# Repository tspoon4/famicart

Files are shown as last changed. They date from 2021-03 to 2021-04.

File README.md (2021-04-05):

# Overview
A while ago, I bought a Famicom in Japan with a bunch of game carts (including Super Mario Bros. 3 and The Legend of Zelda 1!).

As a programmer, I always had in mind to run my own program on it and play with this amazing hardware.
As a beginner in electronics, designing a development cartridge would be an great opportunity to learn.

After a bit of googling, I found the Nesdev community and their extensive [knowledge base](http://wiki.nesdev.com/w/index.php/Nesdev_Wiki). For this learning project, I wanted to design the board from scratch by choosing myself the components and discovering the boolean logic to connect them.

I enjoyed studying the various IC datasheets and playing with the Arduino to prototype the PRG-ROM Flasher.
Please note that this project is not optimized for cost and is not a professional development platform.

# Features
* 512KiB PRG-ROM (Flash) split in 16x32KiB banks
* 64KiB PRG-RAM (SRAM) split in 8x8KiB banks, battery backed work RAM
* 16KiB CHR-RAM (SRAM) with 2-4 nametable support
* Simple discrete logic mapper using an 8bit write-only register at address $8000
	* Bit 0-3: PRG-ROM 32KiB bank selection (2^4 = 16)
	* Bit 4-6: PRG-RAM 8KiB bank selection (2^3 = 8)
	* Bit 7: Software mirroring control (horizontal, vertical)
* CHR-RAM memory mapping customization with 2 jumpers
	* Jumper J2: CIRAM enable/disable
	* Jumper J3: Software controlled mirroring/single-screen
* Arduino Uno/Nano PRG-ROM programmer is available at this [location](flash/)
* KiCad source files for modification are available at this [location](kicad/)
* PDF exports for quick review are available at this [location](pdf/)

# Pictures
Images | Images
------ | ------
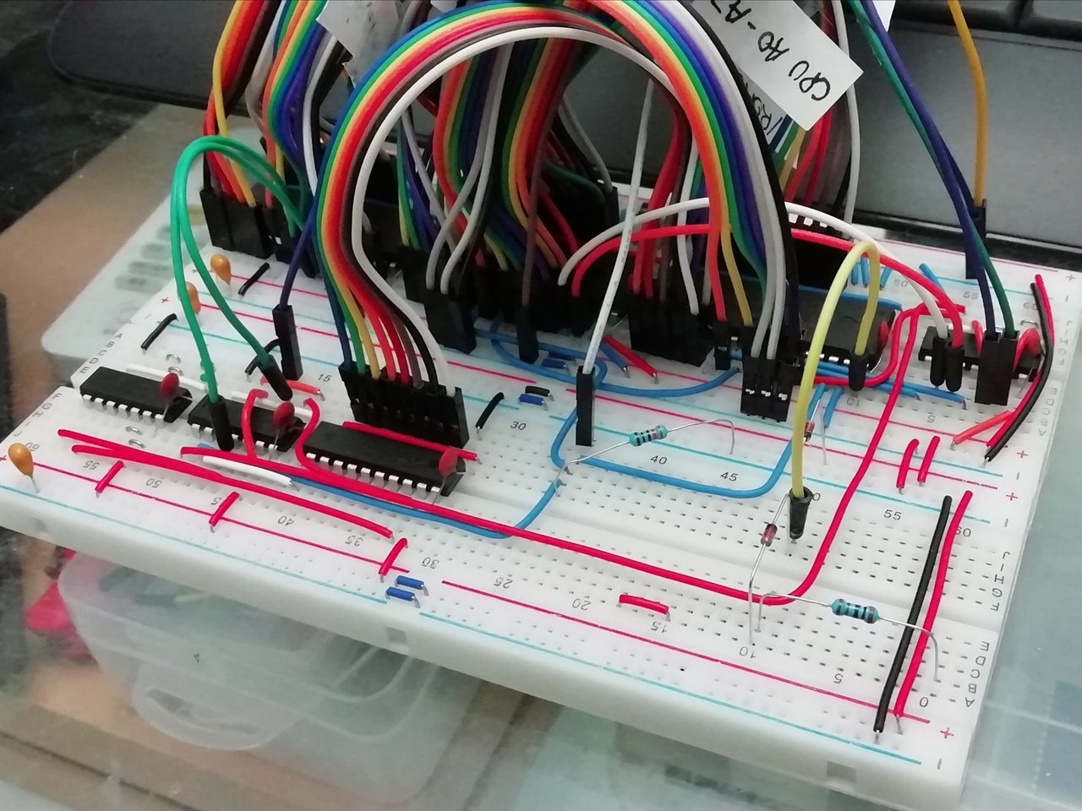
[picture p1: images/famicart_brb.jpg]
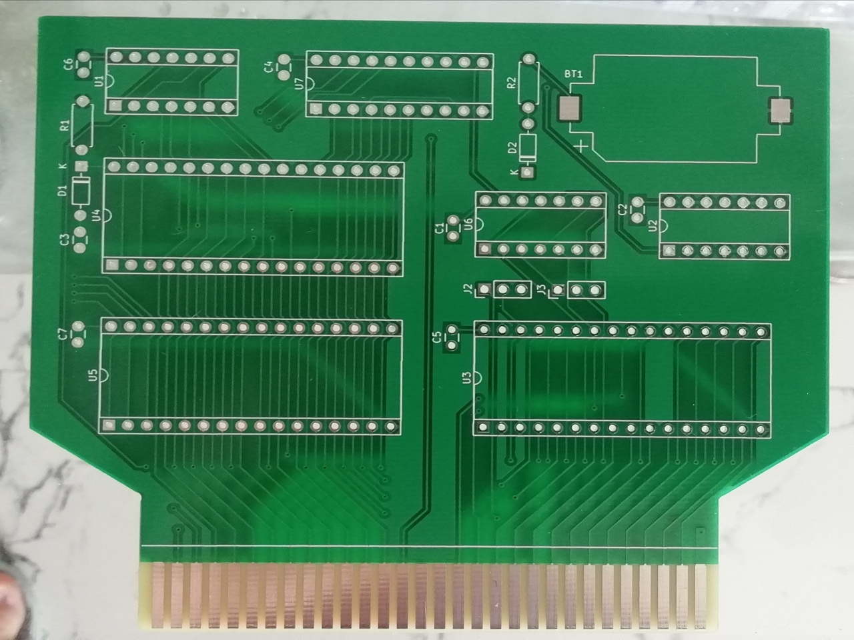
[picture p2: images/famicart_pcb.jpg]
 | 
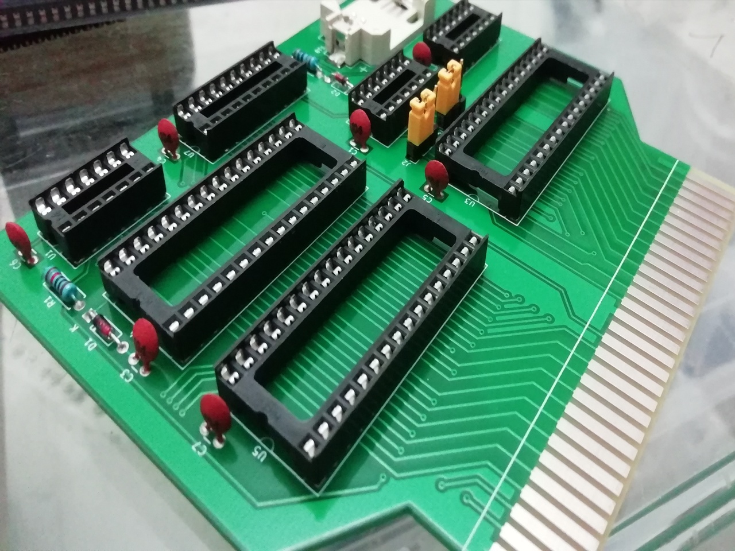
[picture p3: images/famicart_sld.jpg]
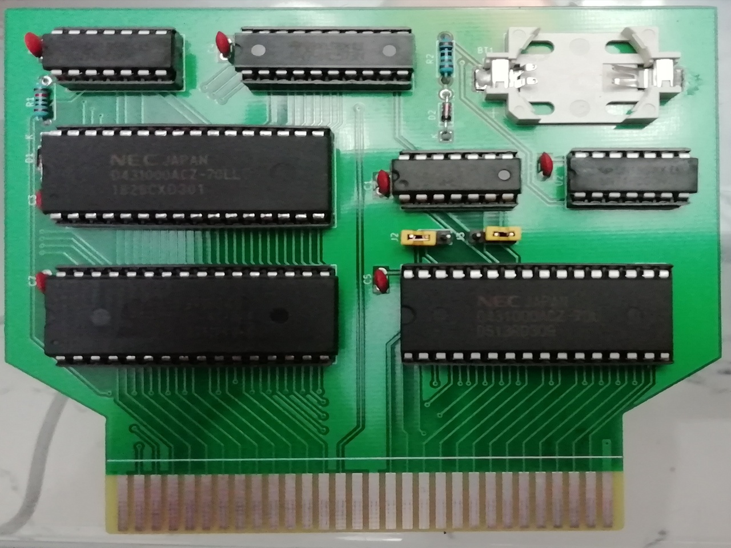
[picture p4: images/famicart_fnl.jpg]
 | 

# Production
To produce the PCB that will fit in the Famicom cartridge slot, you will have to provide to the manufacturer the 2 following items:
* Information that the PCB thickness should be **1.2mm**
* The Gerber files for the different PCB layers from this [location](gerber/)

# Components
Reference | Quantity | Purpose
--------- | -------- | -------
Resistor 1k | 1 | Battery charge protection
Resistor 10k | 1 | Pull down for PRG-RAM
Diode 1N4148 | 2 | Or PRG-RAM power supply
Capacitor 100nF | 7 | Decoupling
Nand 74HC00 | 2 | Decoding PRG R/W signals and misc logic
Nor 74HC02 | 1 | Software controlled mirroring logic
Latch 74HC573 | 1 | Mapper register
Flash SST39SF040 | 1 | PRG-ROM chip
SRAM uPD431000A-70LL | 2 | PRG-RAM and CHR-RAM chip
Conn 3pins | 2 | CHR-RAM jumpers
CR2032 Holder | 1 | 3V battery case

# Potential improvements
### Palette RAM bus conflict when disabling CIRAM
When disabling CIRAM the CHR-RAM is always enabled because:
* CHR-RAM /CE1 is connected to GND
* CHR-RAM CE2 is connected to VCC

CHR-RAM read/write technically mirrors Palette RAM indices but this has not been extensively tested.
### Component packing
Packing is loose and PCB surface use can be improved to reduce costs and fit in a cartridge case.
Vias close to the cartridge connectors might be saved by leveraging memory chip pads.
### CHR-RAM banks instead of PRG-RAM
I've made the choice to implement banking on PRG-RAM instead of CHR-RAM.
It is possible to modify the KiCad source files to use Bit 4-6 of the mapper register to implement banking on CHR-RAM the same way as PRG-RAM.

# References
* [Nesdev wiki](https://wiki.nesdev.com/w/index.php/Cartridge_connector) for the cartridge connector pinout
* [Nesdev forums](https://forums.nesdev.com/viewtopic.php?f=9&t=2162) for the PCB specs and various information
* [KiCad EDA](https://kicad.org/) to edit the PCB source files
* [Arduino Nano](https://store.arduino.cc/usa/arduino-nano) for the links on datasheets
* [NES ca65 example](https://github.com/bbbradsmith/NES-ca65-example) to validate the cartridge features 
* IC Datasheets (TI, SST, NEC)

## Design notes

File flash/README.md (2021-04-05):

# Overview
This folder contains the Famicart SST Flash programmer for the Arduino.

The Arduino program waits for incoming data from the Serial interface.  
It first tries to decode a command and if a command is recognized, it will execute it immediately.  
Input or output data is always transferred from the host PC through the Serial interface.  

The 8bits of data are direcly applied to the SST chip from the Arduino pins.  
The 24bits of address are transferred to the daisy-chained shift registers using the vanilla SPI library.  

The program accepts 3 commands through Serial input:
* **erase**: erases the whole SST chip
* **write \[address\]**: writes at \[address\] the stream of bytes that will follow 
* **read \[address\] \[size\]**: reads at \[address\] an amount of \[size\] bytes and output to tty

# How to use (linux)
Assuming the Arduino is bound to ttyUSB0, first set the device properties
> stty -F /dev/ttyUSB0 speed 115200  
> stty -F /dev/ttyUSB0 raw -echo -echoe -echok  

Then in order to write the SST chip, start by erasing it and then send the command to write the data contained in the program.rom binary file (generally assembled with ca65)
> echo "erase" > /dev/ttyUSB0 ; sleep 1s  
> echo "write 0" > /dev/ttyUSB0 ; cat program.rom > /dev/ttyUSB0  

**Note that in order to succeed, another terminal has to consume the Serial output as follows**
> cat /dev/ttyUSB0  

# Pictures
Image | Image | Image
----- | ----- | -----
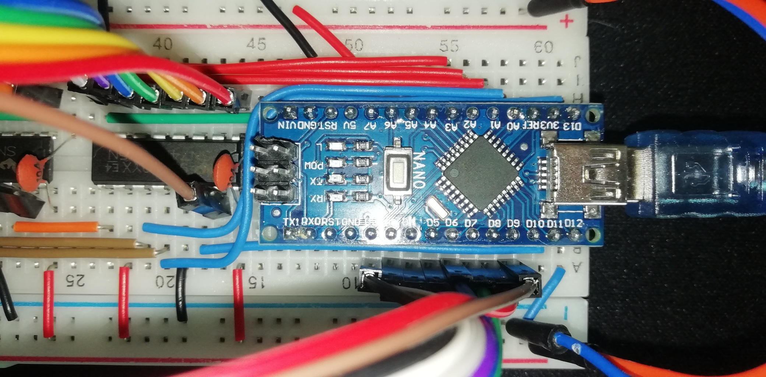
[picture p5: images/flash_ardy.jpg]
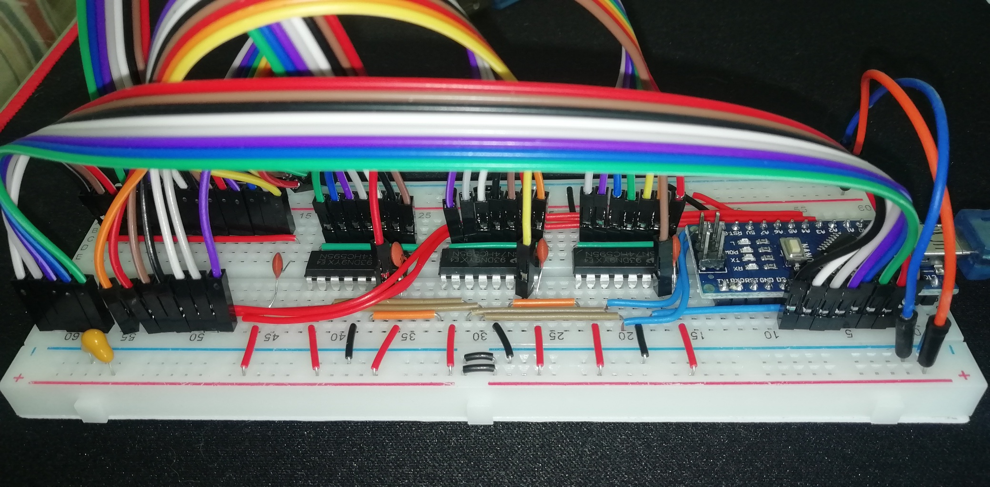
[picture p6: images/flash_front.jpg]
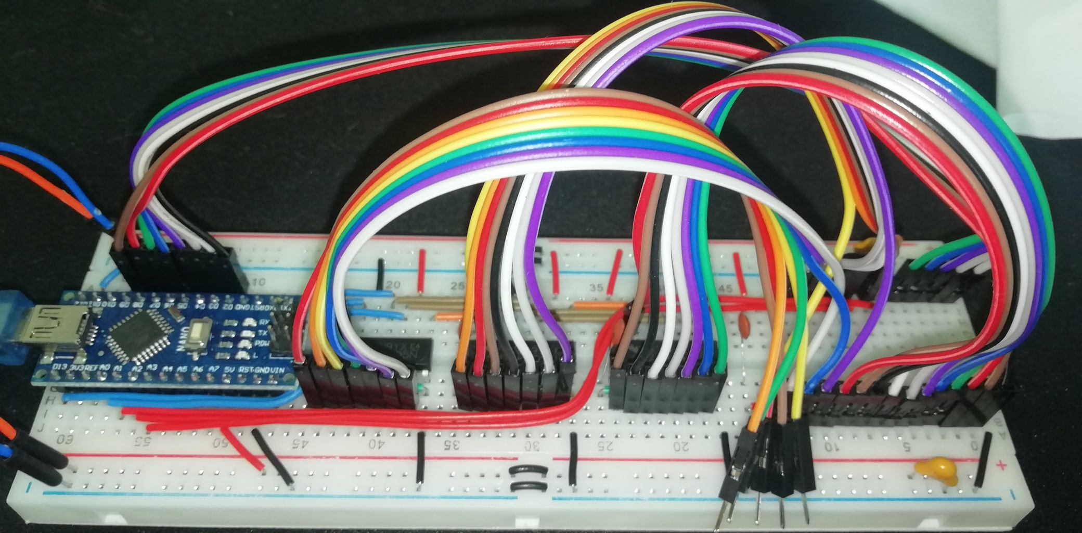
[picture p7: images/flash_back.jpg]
 |  | 

# Components
Reference | Quantity | Purpose
--------- | -------- | -------
Capacitor 100nF | 4 | Decoupling
Capacitor 10uF | 2 | Lower frequency decoupling
Arduino Nano v3.x | 1 | Interface between Host/Flash
Shift 74HC595 | 3 | Arduino pin expansion for address bus (SPI)
Breadboard MB-102 | 1 | A big generic IC socket
Patience | Some | Complete the circuit successfully

# Potential improvements
### Write time is slower than SST theoretical write time
This is probably related to 2 issues:
* Arduino Nano Serial management seems slower than Arduino Uno
* Use of SPI to transfer 24bits addresses (~3us with SPI at 8MHz)

The SST byte program time is ~20us and requires sending 4 commands so 4 addresses in total (~12us). The total time to setup the addresses is not small compared to the byte program time: it's one bottleneck.

It is not possible to set the tty baudrate higher than 115200 without having corruption in this program. This means that the time to transfer a byte is ~87us (3x more than SST byte program time): it's another bottleneck.

As a solution, we can consider using a different microcontroller that has enough pins and supports higher baudrates for Serial transfer.

### Create a PCB
:smile:

# References
* [Arduino SPI reference](https://www.arduino.cc/en/Reference/SPI) to move data to Shift registers
* [Arduino port manipulation](https://www.arduino.cc/en/Reference/PortManipulation) to cut down the pin setup time
* SST Flash Datasheet

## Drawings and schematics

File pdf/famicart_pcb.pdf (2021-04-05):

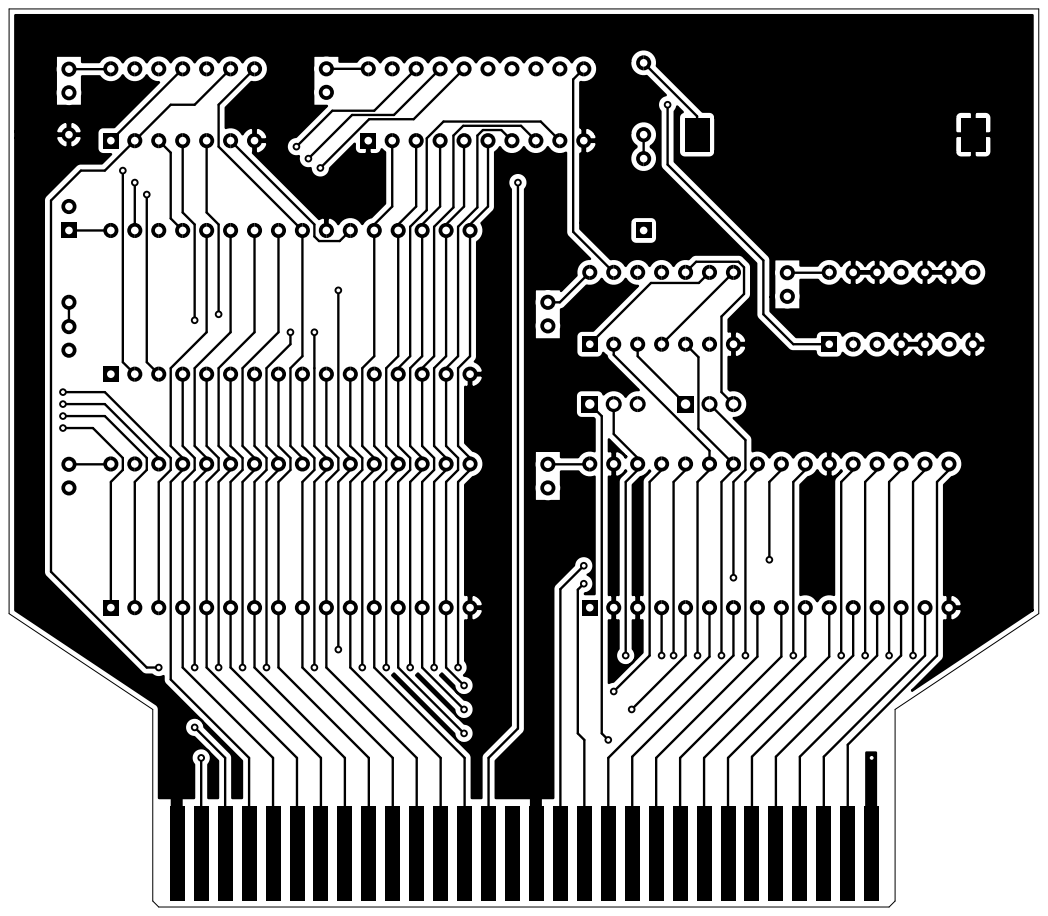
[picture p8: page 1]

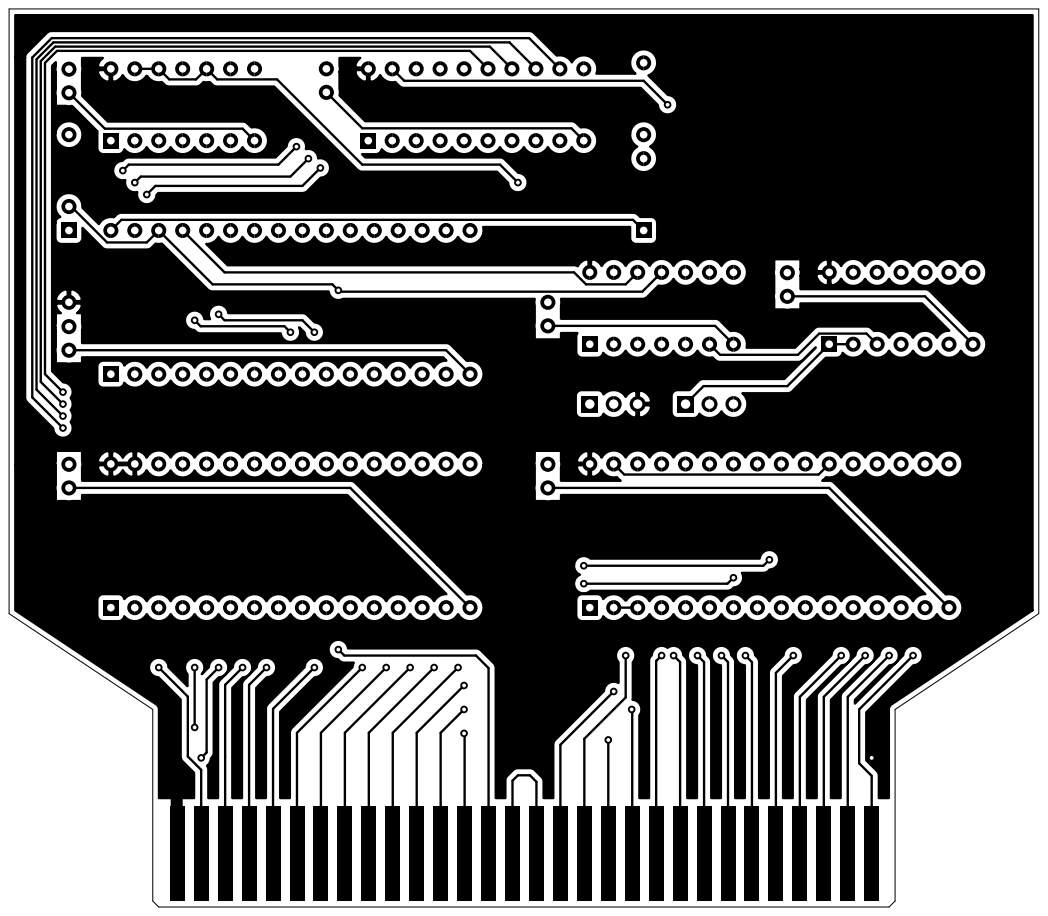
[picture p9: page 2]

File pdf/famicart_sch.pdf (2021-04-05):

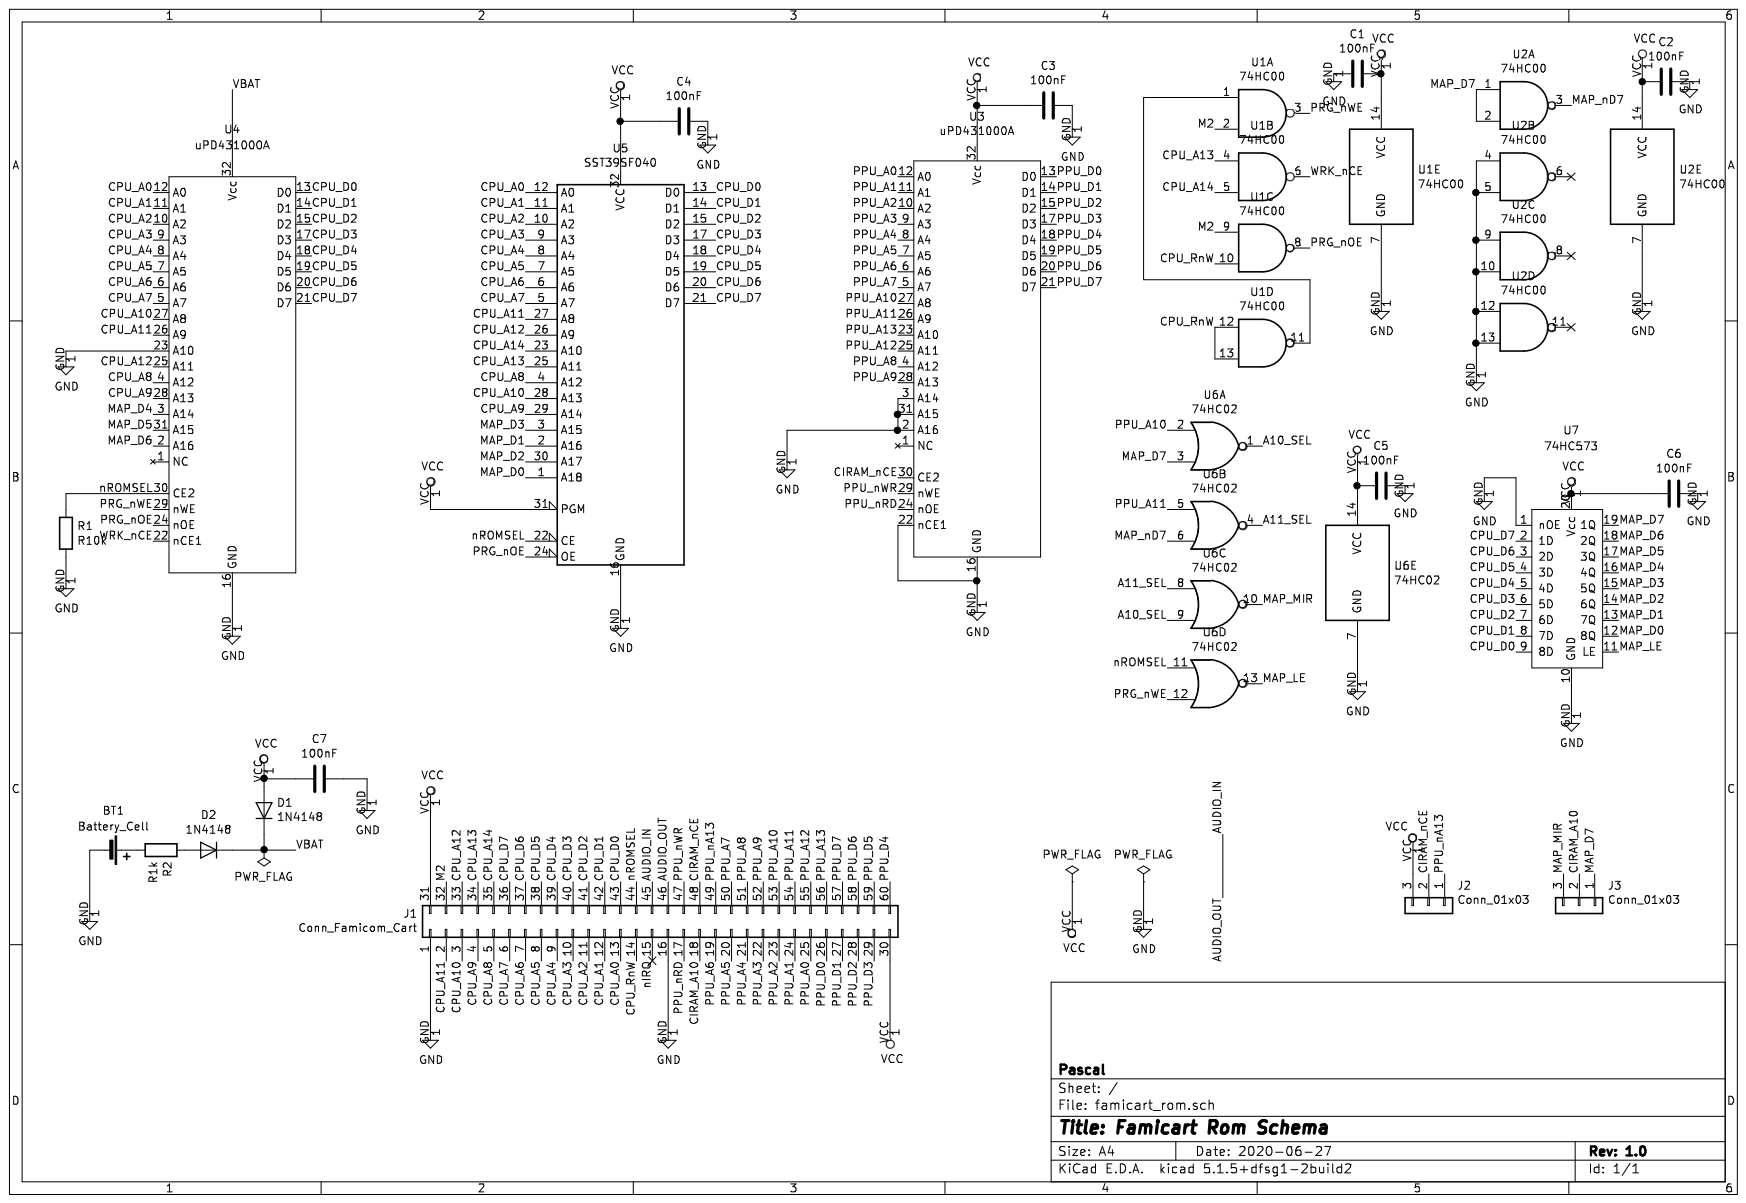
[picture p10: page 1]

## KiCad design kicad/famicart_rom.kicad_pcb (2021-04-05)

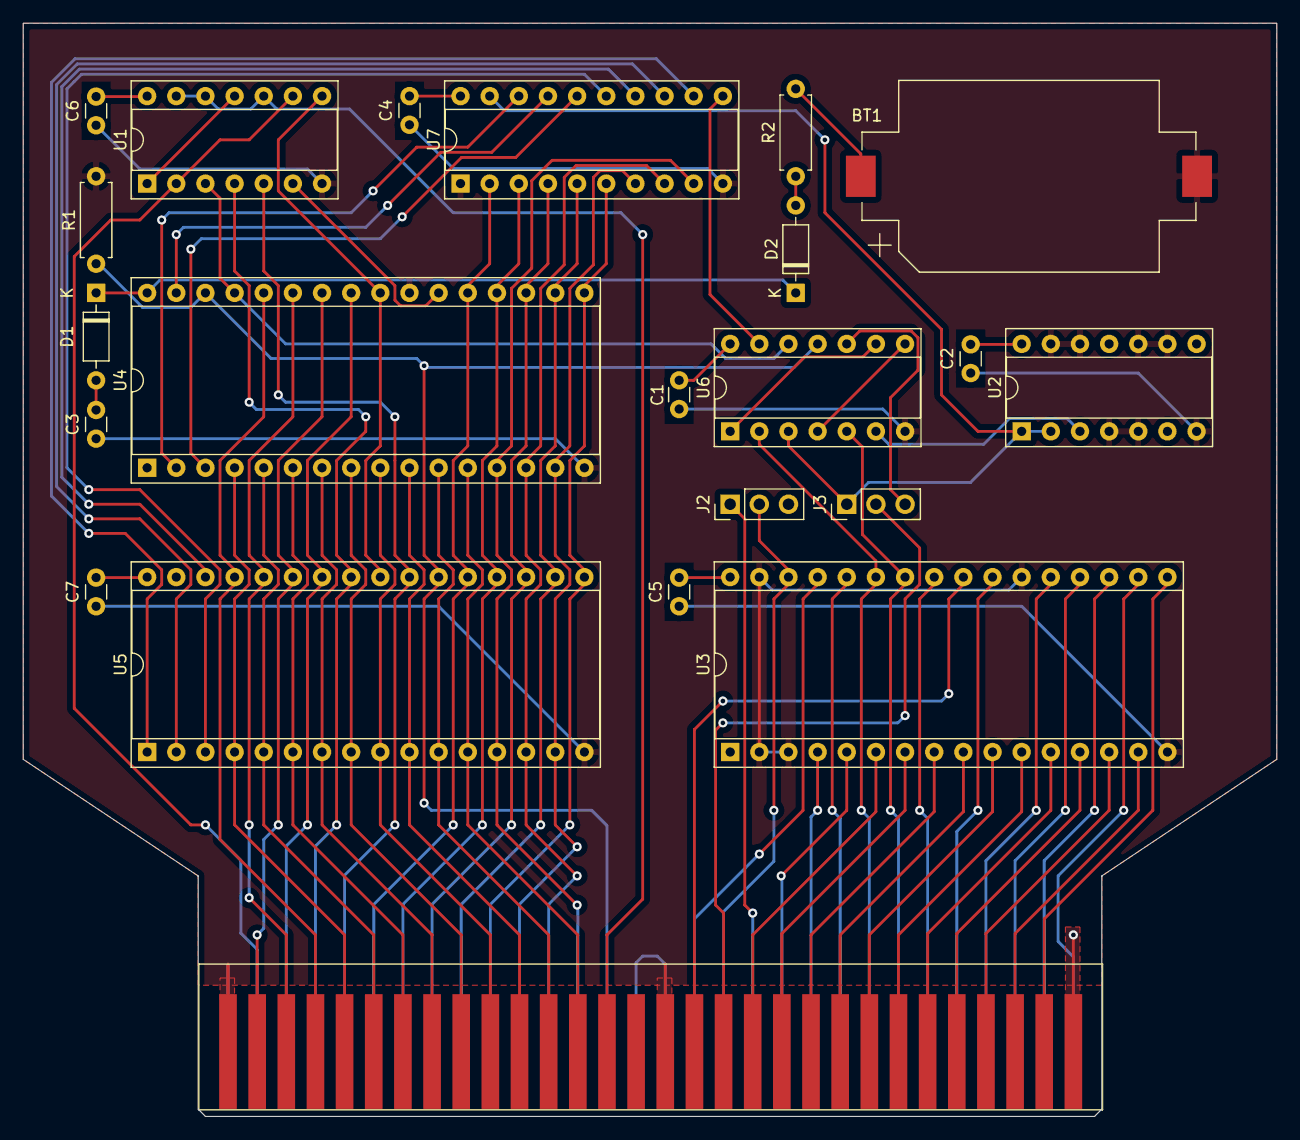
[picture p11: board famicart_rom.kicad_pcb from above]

Board: 2 copper layers, 109.2 x 95.2 mm, 22 parts (0 on the bottom side), 76 nets.

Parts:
BT1: Battery_Cell; BatteryHolder_Keystone_1060_1x2032
C1, C2, C3, C4, C5, C6, C7: 100nF; C_Disc_D3.0mm_W1.6mm_P2.50mm
D1, D2: 1N4148; D_DO-35_SOD27_P7.62mm_Horizontal
J1: Conn_Famicom_Cart; famicom_cart
J2, J3: Conn_01x03; PinHeader_1x03_P2.54mm_Vertical
R1: R10k; R_Axial_DIN0207_L6.3mm_D2.5mm_P7.62mm_Horizontal
R2: R1k; R_Axial_DIN0207_L6.3mm_D2.5mm_P7.62mm_Horizontal
U1, U2: 74HC00; DIP-14_W7.62mm_Socket
U3, U4: uPD431000A; DIP-32_W15.24mm_Socket
U5: SST39SF040; DIP-32_W15.24mm_Socket
U6: 74HC02; DIP-14_W7.62mm_Socket
U7: 74HC573; DIP-20_W7.62mm_Socket

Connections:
/A10_SEL: U6.1, U6.9
/A11_SEL: U6.4, U6.8
/AUDIO_IN: J1.45, J1.46
/CIRAM_A10: J1.18, J3.2
/CIRAM_nCE: J1.48, J2.2, U3.30
/CPU_A0: J1.13, U4.12, U5.12
/CPU_A1: J1.12, U4.11, U5.11
/CPU_A2: J1.11, U4.10, U5.10
/CPU_A3: J1.10, U4.9, U5.9
/CPU_A4: J1.9, U4.8, U5.8
/CPU_A5: J1.8, U4.7, U5.7
/CPU_A6: J1.7, U4.6, U5.6
/CPU_A7: J1.6, U4.5, U5.5
/CPU_A8: J1.5, U4.4, U5.4
/CPU_A9: J1.4, U4.28, U5.29
/CPU_A10: J1.3, U4.27, U5.28
/CPU_A11: J1.2, U4.26, U5.27
/CPU_A12: J1.33, U4.25, U5.26
/CPU_A13: J1.34, U1.4, U5.25
/CPU_A14: J1.35, U1.5, U5.23
/CPU_D0: J1.43, U4.13, U5.13, U7.9
/CPU_D1: J1.42, U4.14, U5.14, U7.8
/CPU_D2: J1.41, U4.15, U5.15, U7.7
/CPU_D3: J1.40, U4.17, U5.17, U7.6
/CPU_D4: J1.39, U4.18, U5.18, U7.5
/CPU_D5: J1.38, U4.19, U5.19, U7.4
/CPU_D6: J1.37, U4.20, U5.20, U7.3
/CPU_D7: J1.36, U4.21, U5.21, U7.2
/CPU_RnW: J1.14, U1.10, U1.12, U1.13
/M2: J1.32, U1.2, U1.9
/MAP_D0: U5.1, U7.12
/MAP_D1: U5.2, U7.13
/MAP_D2: U5.30, U7.14
/MAP_D3: U5.3, U7.15
/MAP_D4: U4.3, U7.16
/MAP_D5: U4.31, U7.17
/MAP_D6: U4.2, U7.18
/MAP_D7: J3.1, U2.1, U2.2, U6.3, U7.19
/MAP_LE: U6.13, U7.11
/MAP_MIR: J3.3, U6.10
/MAP_nD7: U2.3, U6.6
/PPU_A0: J1.25, U3.12
/PPU_A1: J1.24, U3.11
/PPU_A2: J1.23, U3.10
/PPU_A3: J1.22, U3.9
/PPU_A4: J1.21, U3.8
/PPU_A5: J1.20, U3.7
/PPU_A6: J1.19, U3.6
/PPU_A7: J1.50, U3.5
/PPU_A8: J1.51, U3.4
/PPU_A9: J1.52, U3.28
/PPU_A10: J1.53, U3.27, U6.2
/PPU_A11: J1.54, U3.26, U6.5
/PPU_A12: J1.55, U3.25
/PPU_A13: J1.56, U3.23
/PPU_D0: J1.26, U3.13
/PPU_D1: J1.27, U3.14
/PPU_D2: J1.28, U3.15
/PPU_D3: J1.29, U3.17
/PPU_D4: J1.60, U3.18
/PPU_D5: J1.59, U3.19
/PPU_D6: J1.58, U3.20
/PPU_D7: J1.57, U3.21
/PPU_nA13: J1.49, J2.1
/PPU_nRD: J1.17, U3.24
/PPU_nWR: J1.47, U3.29
/PRG_nOE: U1.8, U4.24, U5.24
/PRG_nWE: U1.3, U4.29, U6.12
/VBAT: D1.1, D2.1, U4.32
/WRK_nCE: U1.6, U4.22
/nROMSEL: J1.44, R1.1, U4.30, U5.22, U6.11
GND: BT1.2, C1.2, C2.1, C3.1, C4.1, C5.1, C6.1, C7.1, J1.1, J1.16, R1.2, U1.7, U2.4, U2.5, U2.7, U2.9, U2.10, U2.12, U2.13, U3.2, U3.3, U3.16, U3.22, U3.31, U4.16, U4.23, U5.16, U6.7, U7.1, U7.10
unnamed: BT1.1, R2.2
unnamed: D2.2, R2.1
unnamed: U1.1, U1.11
VCC: C1.1, C2.2, C3.2, C4.2, C5.2, C6.2, C7.2, D1.2, J1.30, J1.31, J2.3, U1.14, U2.14, U3.32, U5.31, U5.32, U6.14, U7.20

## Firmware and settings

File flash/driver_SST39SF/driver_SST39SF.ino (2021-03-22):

#include <SPI.h>

#define PORTC_RCLK  0x01
#define PORTC_NOE   0x02
#define PORTC_NWE   0x04
#define PORTC_NCE   0x08

#define PORTB_DATA 0x03
#define PORTD_DATA 0xfc
#define PORTC_CTRL 0x0f

#define SRL_BAUDS 115200
#define SRL_TIMEOUT 100
#define SPI_FREQ 8000000

#define INPUT_SIZE 32
#define NOP __asm__("nop\n\t")

// Normal
//#define CMD_5555 0x5555L
//#define CMD_2AAA 0x2aaaL

// Breadboard
//#define CMD_5555 0xa955L
//#define CMD_2AAA 0x16aaL

// Famicart
#define CMD_5555 0x4b55L
#define CMD_2AAA 0x34aaL


static void romDisableMode()
{ 
  // Various control
  PORTC &= ~PORTC_RCLK; // Set Shift register clock low
  PORTC |= PORTC_NOE;   // Disable memory read (not) using pull-up
  PORTC |= PORTC_NWE;   // Disable memory write (not) using pull-up
  PORTC |= PORTC_NCE;   // Disable memory chip (not) using pull-up
  DDRC &= ~PORTC_CTRL;

  // Data read
  PORTB &= ~PORTB_DATA;
  PORTD &= ~PORTD_DATA;
  DDRB &= ~PORTB_DATA;
  DDRD &= ~PORTD_DATA;
}


static void romWriteMode()
{
  // Various controls  
  PORTC &= ~PORTC_RCLK; // Set Shift register clock low
  PORTC |= PORTC_NOE;  // Disable memory read (not)
  PORTC |= PORTC_NWE;  // Disable memory write (not)
  PORTC &= ~PORTC_NCE;
  DDRC |= PORTC_CTRL;
  
  // Data write
  PORTB &= ~PORTB_DATA;
  PORTD &= ~PORTD_DATA;
  DDRB |= PORTB_DATA;
  DDRD |= PORTD_DATA;
}


static inline void romWriteAddress(long _address)
{
  byte tmp[3];
  tmp[0] = (byte) (_address & 0xff);
  tmp[1] = (byte) ((_address >> 8) & 0xff);
  tmp[2] = (byte) ((_address >> 16) & 0xff);
  
  SPI.transfer(tmp, 3);

  PORTC |= PORTC_RCLK;
  PORTC &= ~PORTC_RCLK;
}


static inline void romWriteData(byte _value)
{
  PORTB = (PORTB & ~PORTB_DATA) | (_value & PORTB_DATA);
  PORTD = (PORTD & ~PORTD_DATA) | (_value & PORTD_DATA);  
  PORTC &= ~PORTC_NWE;
  NOP;
  NOP;
  PORTC |= PORTC_NWE;
}


static inline void romWrite(long _address, byte _value)
{
  romWriteAddress(_address);
  romWriteData(_value);
}


static void romReadMode()
{
  // Various controls  
  PORTC &= ~PORTC_RCLK; // Set Shift register clock low
  PORTC |= PORTC_NOE;  // Disable memory read (not)
  PORTC |= PORTC_NWE;  // Disable memory write (not)
  PORTC &= ~PORTC_NCE;
  DDRC |= PORTC_CTRL;
  
  // Data read
  PORTB &= ~PORTB_DATA;
  PORTD &= ~PORTD_DATA;
  DDRB &= ~PORTB_DATA;
  DDRD &= ~PORTD_DATA;
}


static inline byte romReadData()
{
  byte value = 0;
  PORTC &= ~PORTC_NOE;
  NOP;
  NOP;
  value |= PINB & PORTB_DATA;
  value |= PIND & PORTD_DATA;
  PORTC |= PORTC_NOE;
  return value;
}


static inline byte romRead(long _address)
{
  romWriteAddress(_address);
  return romReadData();
}


static byte split(char *_string, const char *_delimiter, const char *_tokens[8])
{
  byte count = 0;
  char *token = strtok(_string, _delimiter);
  while(token != NULL && count < 8)
  {
    _tokens[count++] = token;
    token = strtok(NULL, _delimiter);    
  }
  return count;
}


void setup()
{
  // Read TCNT1 to do cycle timing
  TCCR1A = 0;
  TCCR1B = 1;

  romDisableMode();
  SPI.begin();
  Serial.begin(SRL_BAUDS);
  Serial.setTimeout(SRL_TIMEOUT);
  SPI.beginTransaction(SPISettings(SPI_FREQ, LSBFIRST, SPI_MODE0));
}


void loop()
{
  char command[INPUT_SIZE];
  size_t count = Serial.readBytesUntil('\n', command, INPUT_SIZE);
  if(count > 0)
  {
    // Parse the command
    command[count] = 0;
    const char *tokens[8];
    byte argc = split(command, " ", tokens);
    if(argc > 0)
    {
      if(strcmp(tokens[0], "write") == 0 && argc == 2)
      {
        size_t count = 0;
        byte data[INPUT_SIZE];
        long ptr = atol(tokens[1]);
        
        while((count = Serial.readBytes(data, INPUT_SIZE)) > 0)
        {
          for(size_t i = 0; i < count; ++i)
          {
            romWriteMode();
            byte last = data[i];
            
            romWrite(CMD_5555, 0xaa);
            romWrite(CMD_2AAA, 0x55);
            romWrite(CMD_5555, 0xa0);
            
            romWrite(ptr++, last);

            romReadMode();
            while((romReadData() & 0x80) != (last & 0x80));
          }
        }
        romDisableMode();
      }
      else if(strcmp(tokens[0], "read") == 0 && argc == 3)
      {
        byte data[INPUT_SIZE];
        long ptr = atol(tokens[1]);
        long count = atol(tokens[2]);
        
        romReadMode();
        while(count > 0)
        {
          long readsize = (count > INPUT_SIZE) ? INPUT_SIZE : count;
          
          for(long i = 0; i < readsize; ++i)
            data[i] = romRead(ptr++);

          count -= readsize;
          Serial.write(data, readsize);
        }
        romDisableMode();
      }
      else if(strcmp(tokens[0], "erase") == 0 && argc == 1)
      {
        romWriteMode();        
        romWrite(CMD_5555, 0xaa);
        romWrite(CMD_2AAA, 0x55);
        romWrite(CMD_5555, 0x80);
        romWrite(CMD_5555, 0xaa);
        romWrite(CMD_2AAA, 0x55);
        romWrite(CMD_5555, 0x10);

        romReadMode();
        while((romReadData() & 0x80) != (0x10 & 0x80));
        Serial.println("erased!");
          
        romDisableMode();
      }
    }
  }
}

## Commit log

2021-03-22 Add most of the content, still have to complete *.md files
    [famicart_rom-B_Cu.gbl, famicart_rom-B_Mask.gbs, famicart_rom-B_Paste.gbp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]
2021-04-05 Integrated jero32 feedback: pdf export and connector mask update
    [famicart_rom-B_Cu.gbl, famicart_rom-B_Mask.gbs, famicart_rom-B_Paste.gbp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]
